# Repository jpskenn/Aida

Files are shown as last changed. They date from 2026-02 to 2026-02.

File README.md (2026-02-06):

# Aida（アイーダ）

Yet another split keyboard, based on SandyLP.

Aida is a 40% split keyboard with symmetrical row staggered layout and key height optimization.

---

Aidaは左右対称ロースタッガード配列の40%分割型キーボードで、スイッチの配置を立体的にして高さ方向への最適化をおこなっています。

前機種の[SandyLP](https://github.com/jpskenn/SandyLP)を元に、分割型へ派生しました。

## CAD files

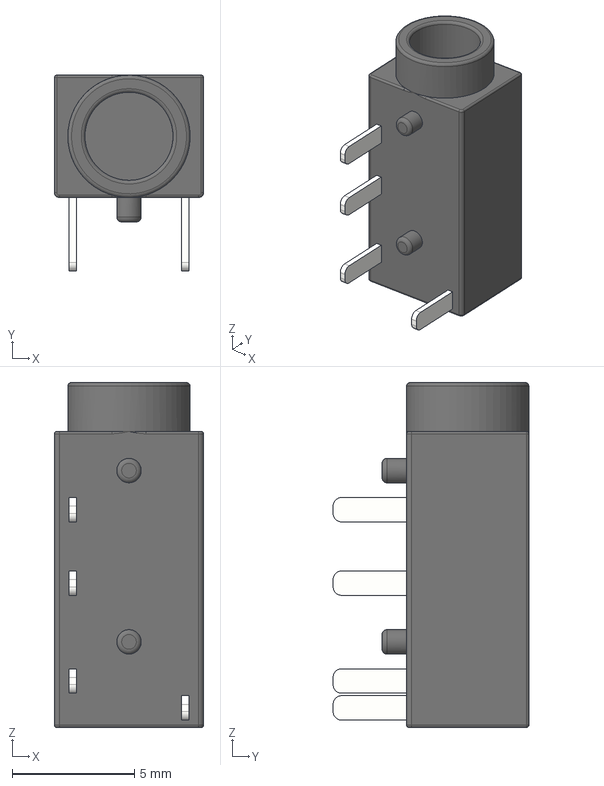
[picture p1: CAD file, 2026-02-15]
PCB/Aida_Under_Cover/Lib_Local/PJ-320A.step
6.10 x 8.00 x 14.1 mm

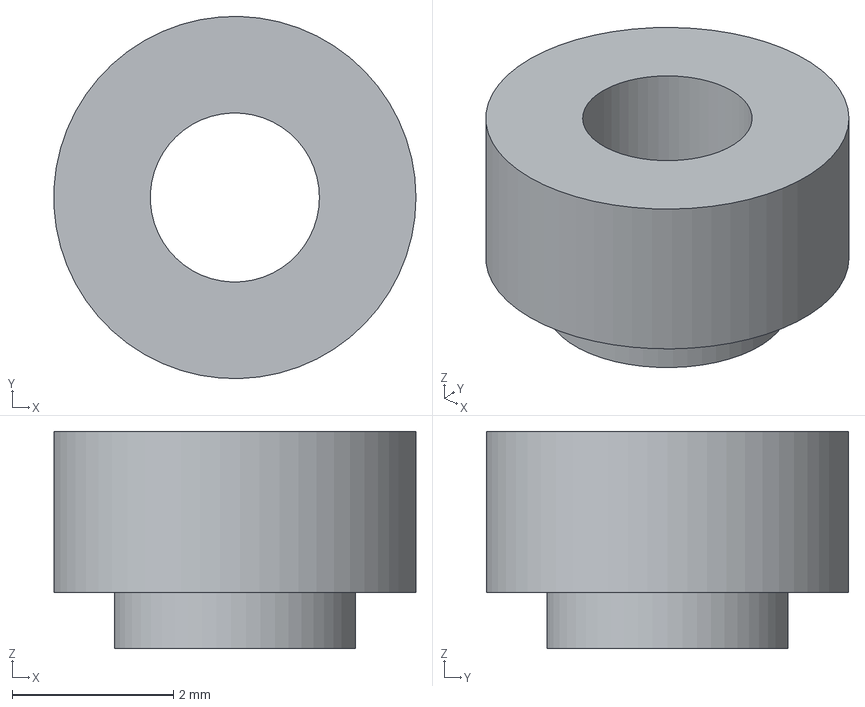
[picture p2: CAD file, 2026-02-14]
PCB/Aida_Under_Cover/Lib_Local/ThroughHole-Tap_THC-0.8-2.0-2-Fusion.step
4.50 x 4.50 x 2.70 mm

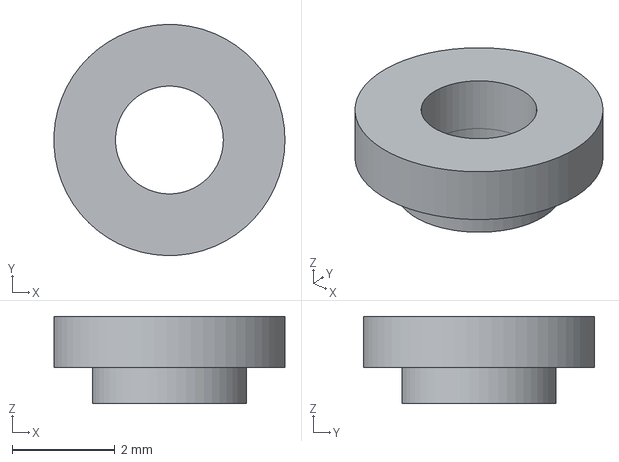
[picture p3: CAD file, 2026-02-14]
PCB/Aida_Under_Cover/Lib_Local/ThroughHole-Tap_THC-0.8-1.0-2-Fusion.step
4.50 x 4.50 x 1.70 mm

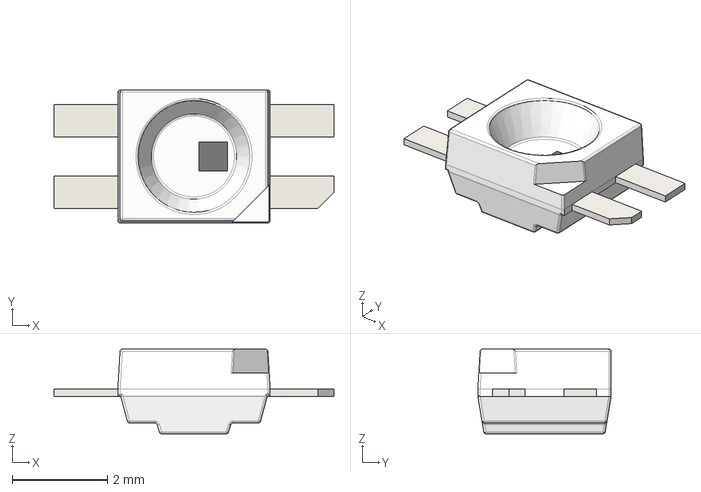
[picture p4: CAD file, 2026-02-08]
PCB/Aida_Under_Cover/Lib_Local/LED_SK6812MINI-E.step
5.88 x 2.80 x 1.78 mm

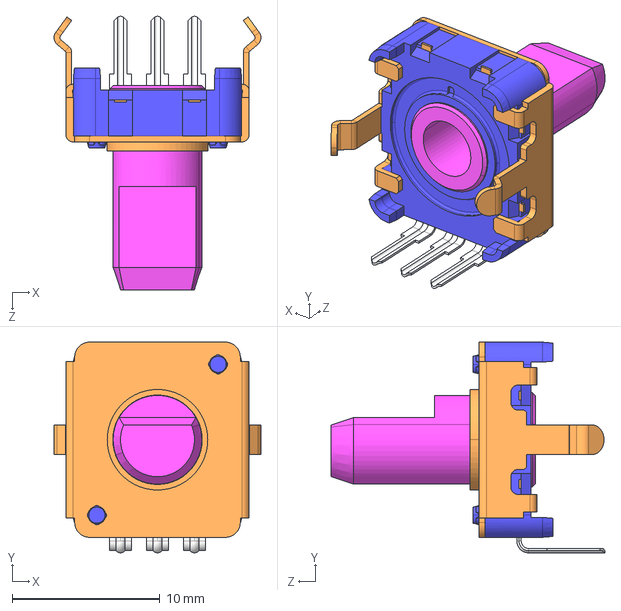
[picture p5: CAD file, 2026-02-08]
PCB/Aida_Under_Cover/Lib_Local/EC12E-150.STEP
14.0 x 14.2 x 18.5 mm

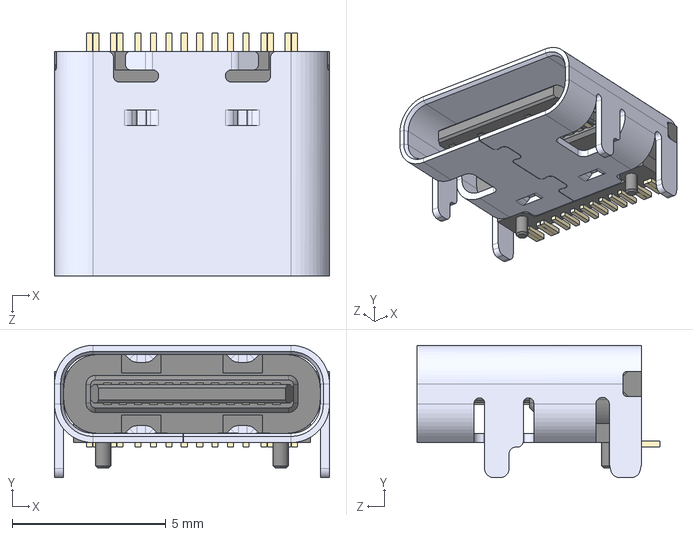
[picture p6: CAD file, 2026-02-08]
PCB/Aida_Under_Cover/Lib_Local/TYPE-C-31-M-12--3DModel-STEP-56544.STEP
8.94 x 4.30 x 7.90 mm

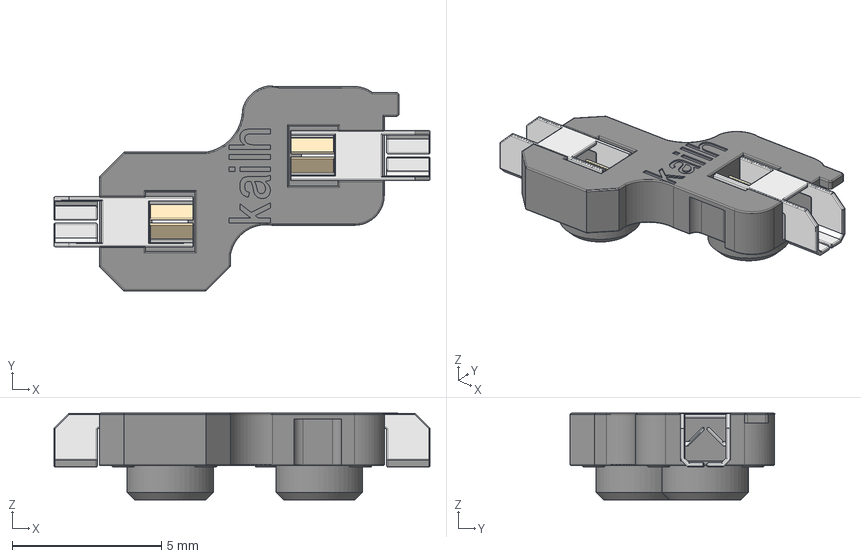
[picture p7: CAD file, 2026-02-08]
PCB/Aida_Under_Cover/Lib_Local/kailh-socket-choc.stp
12.6 x 6.87 x 2.90 mm
metal-contact1
metal-contact2
plastic-body

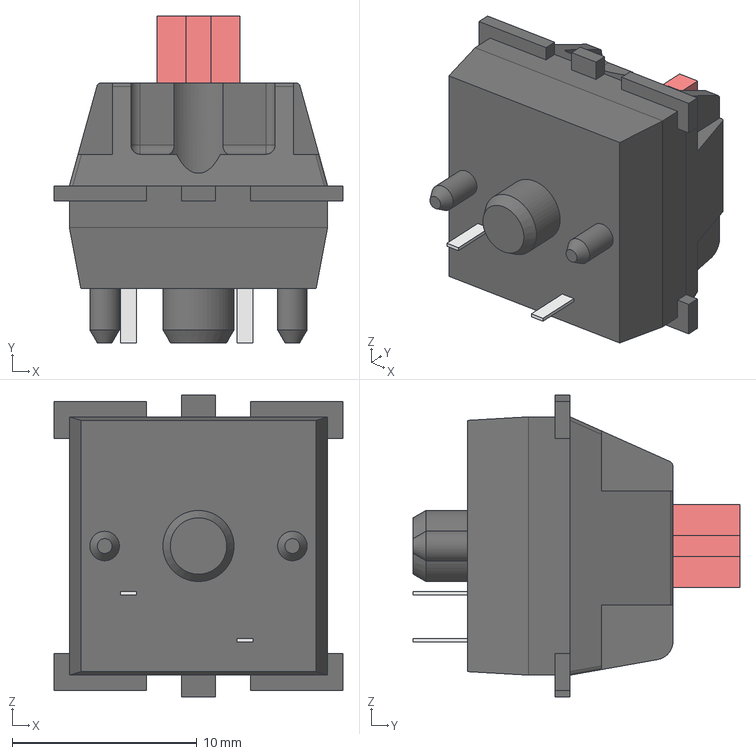
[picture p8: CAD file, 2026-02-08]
PCB/Aida_Under_Cover/Lib_Local/mx-switch.step
15.6 x 17.7 x 16.3 mm

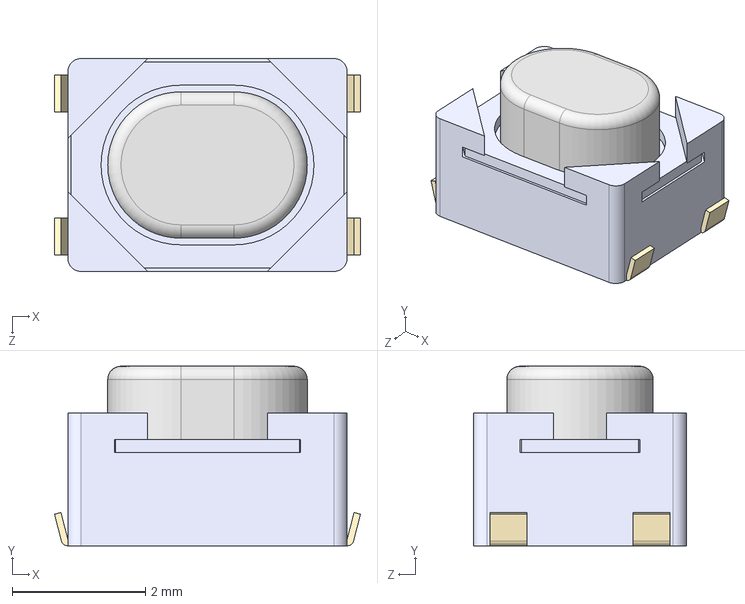
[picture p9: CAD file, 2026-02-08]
PCB/Aida_Under_Cover/Lib_Local/PTS810_SJM_250_SMTR_LFS.step
4.60 x 2.70 x 3.20 mm

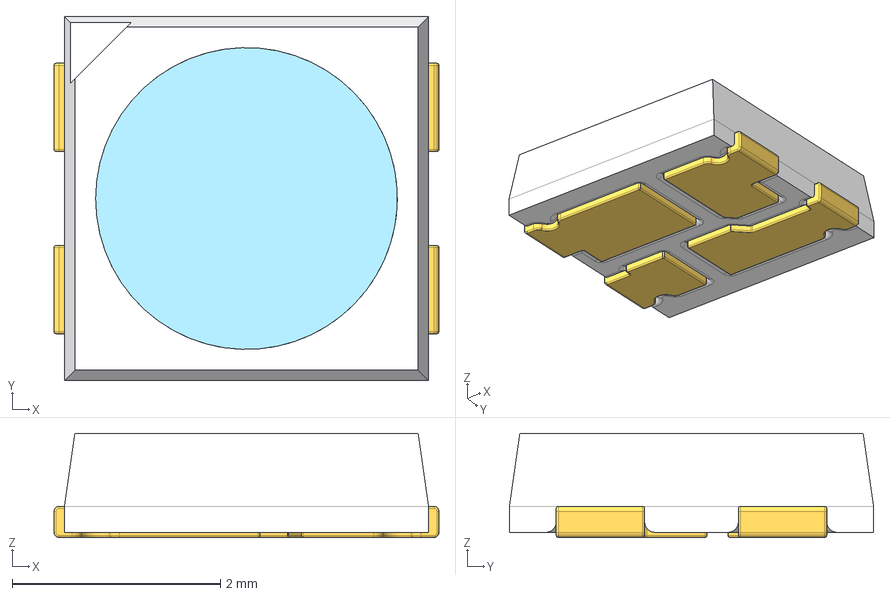
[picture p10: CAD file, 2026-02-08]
PCB/Aida_Under_Cover/Lib_Local/SMD3535 RGB.stp
3.70 x 3.50 x 1.00 mm

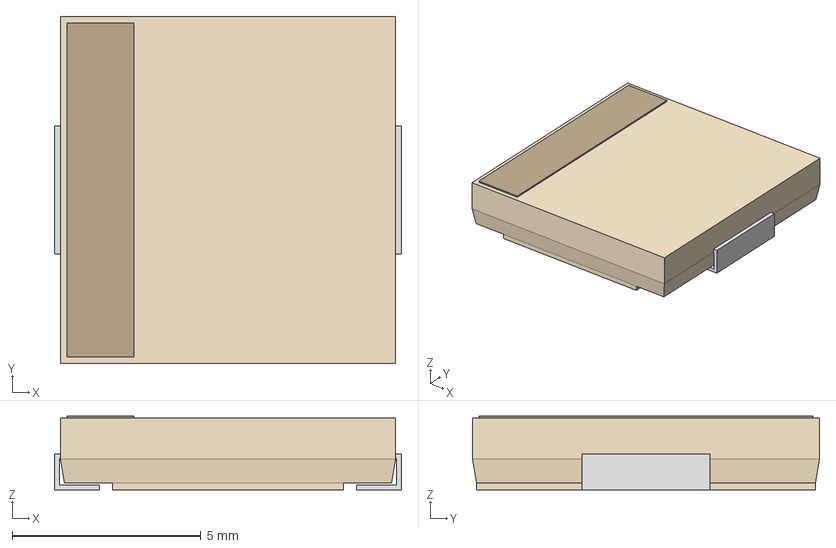
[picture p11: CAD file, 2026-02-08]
PCB/Aida_Under_Cover/Lib_Local/PKMCS0909E4000-R1_MUR.step
9.19 x 9.19 x 1.96 mm

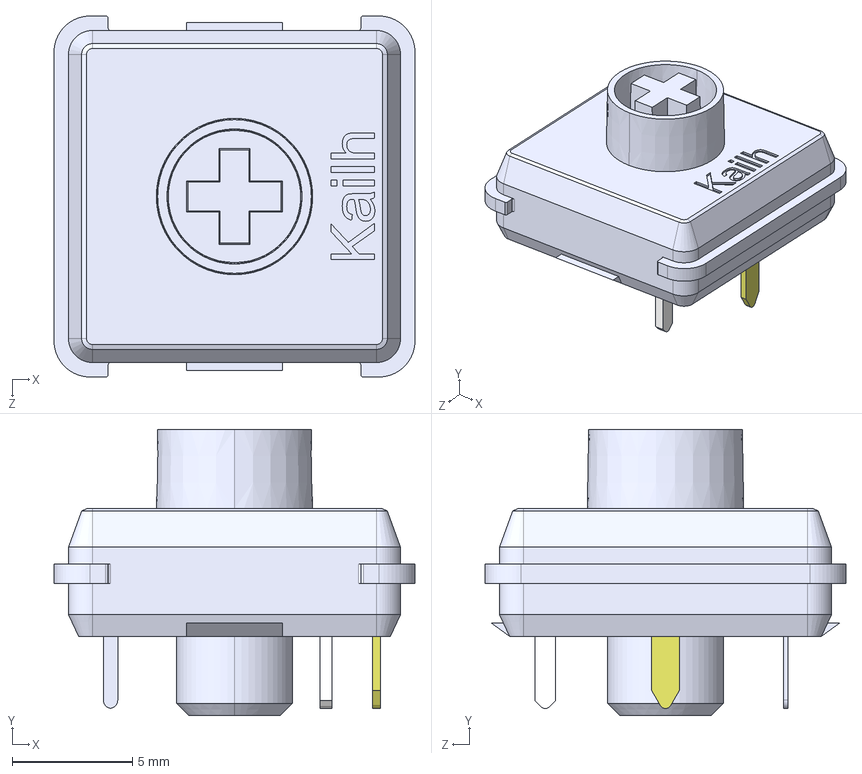
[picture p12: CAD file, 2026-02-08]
PCB/Aida_Under_Cover/Lib_Local/Kailh_PG1353.STEP
15.0 x 11.9 x 15.0 mm

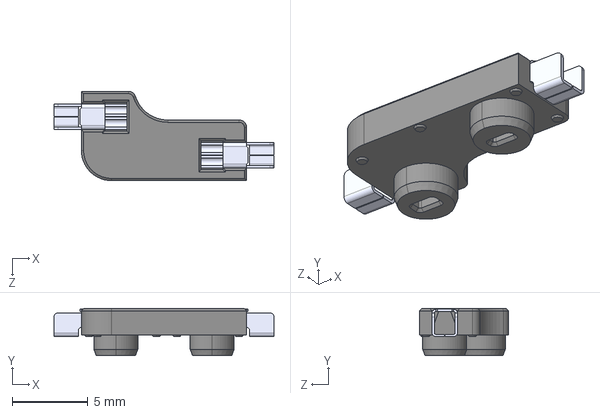
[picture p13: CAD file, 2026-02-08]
PCB/Aida_Under_Cover/Lib_Local/MX_Socket_PG151101S11.STEP
14.5 x 3.10 x 5.89 mm

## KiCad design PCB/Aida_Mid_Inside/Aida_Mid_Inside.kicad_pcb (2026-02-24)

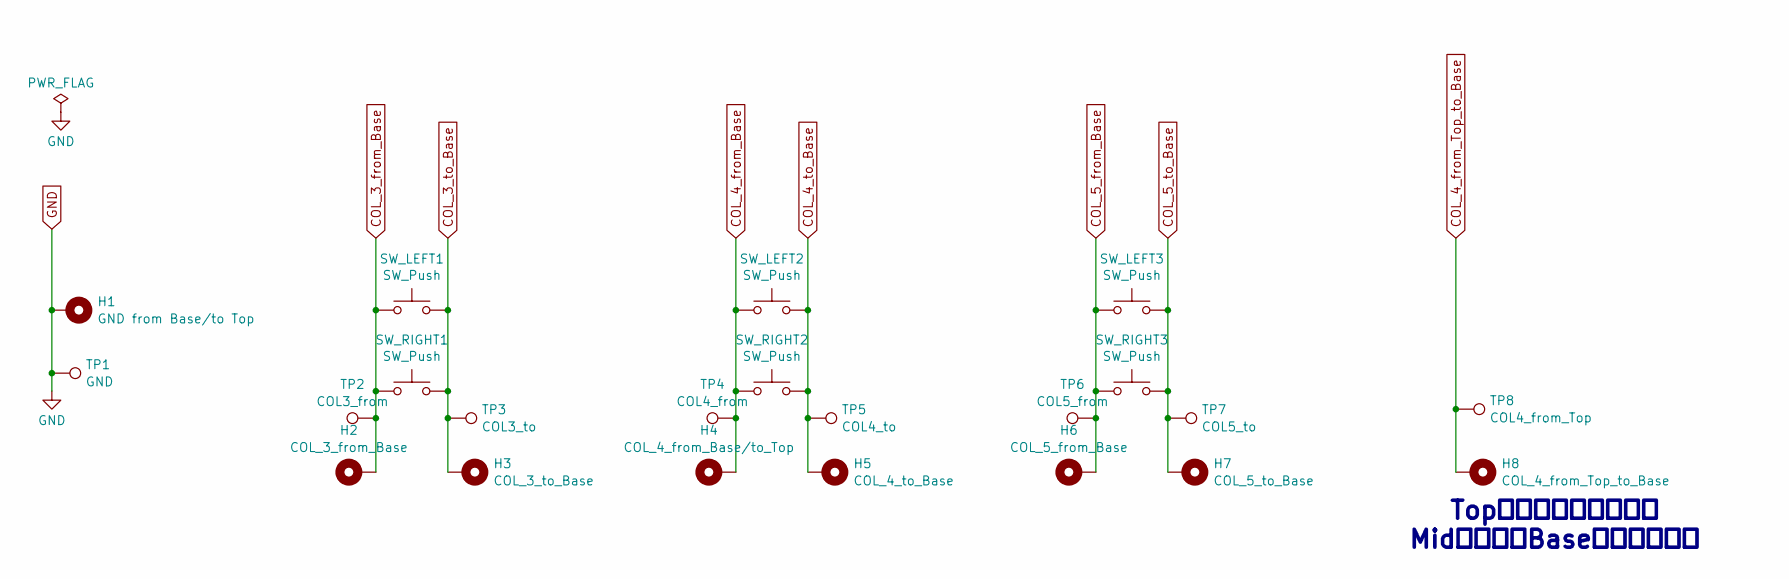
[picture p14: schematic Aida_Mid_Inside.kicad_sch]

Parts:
H1: GND from Base/to Top; MountingHole_2.2mm_M2_Pad_minimal
H2: COL_3_from_Base; MountingHole_M2_Through-hole_tap_THC-0.8-1.0-2_minimal
H3: COL_3_to_Base; MountingHole_M2_Through-hole_tap_THC-0.8-1.0-2_minimal
H4: COL_4_from_Base/to_Top; MountingHole_2.2mm_M2_Pad_minimal
H5: COL_4_to_Base; MountingHole_M2_Through-hole_tap_THC-0.8-1.0-2_minimal
H6: COL_5_from_Base; MountingHole_2.2mm_M2_Pad_minimal
H7: COL_5_to_Base; MountingHole_2.2mm_M2_Pad_minimal
H8: COL_4_from_Top_to_Base; MountingHole_2.2mm_M2_Pad_minimal
SW_LEFT1, SW_LEFT2, SW_LEFT3: SW_Push; Kailh_socket_ChocV2_small_#2pad_for_Reverse_no_hole
SW_RIGHT1, SW_RIGHT2, SW_RIGHT3: SW_Push; Kailh_socket_ChocV2_for_Reverse
TP1: GND; PinHeader_1x01_P2.00mm_Vertical
TP2: COL3_from; PinHeader_1x01_P2.00mm_Vertical
TP3: COL3_to; PinHeader_1x01_P2.00mm_Vertical
TP4: COL4_from; PinHeader_1x01_P2.00mm_Vertical
TP5: COL4_to; PinHeader_1x01_P2.00mm_Vertical
TP6: COL5_from; PinHeader_1x01_P2.00mm_Vertical
TP7: COL5_to; PinHeader_1x01_P2.00mm_Vertical
TP8: COL4_from_Top; PinHeader_1x01_P2.00mm_Vertical

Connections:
COL_3_from_Base: H2.1, SW_LEFT1.1, SW_RIGHT1.1, TP2.1
COL_3_to_Base: H3.1, SW_LEFT1.2, SW_RIGHT1.2, TP3.1
COL_4_from_Base: H4.1, SW_LEFT2.1, SW_RIGHT2.1, TP4.1
COL_4_from_Top_to_Base: H8.1, TP8.1
COL_4_to_Base: H5.1, SW_LEFT2.2, SW_RIGHT2.2, TP5.1
COL_5_from_Base: H6.1, SW_LEFT3.1, SW_RIGHT3.1, TP6.1
COL_5_to_Base: H7.1, SW_LEFT3.2, SW_RIGHT3.2, TP7.1
GND: H1.1, TP1.1

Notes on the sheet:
Topのスイッチ出力は、 Midとは別にBaseへ伝達する。

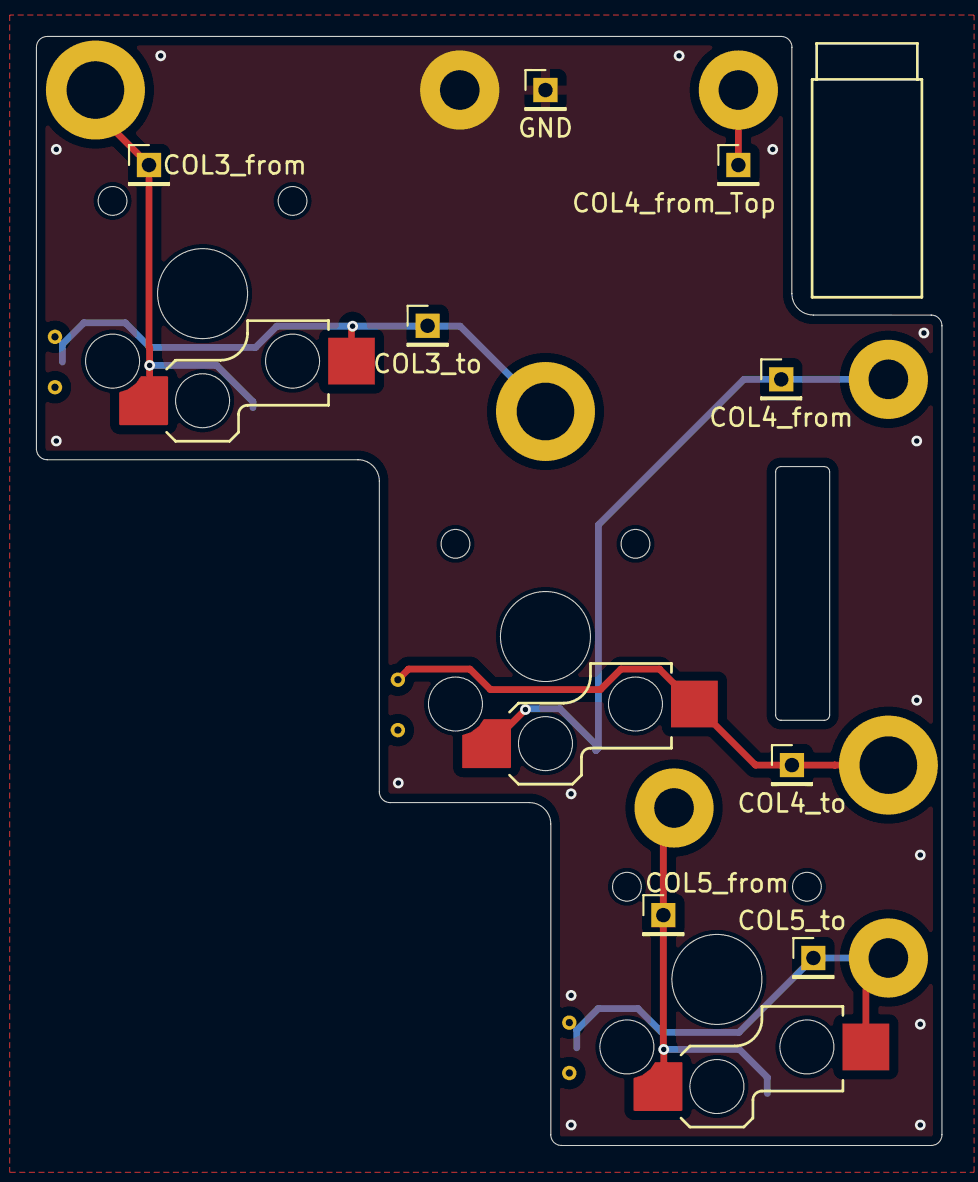
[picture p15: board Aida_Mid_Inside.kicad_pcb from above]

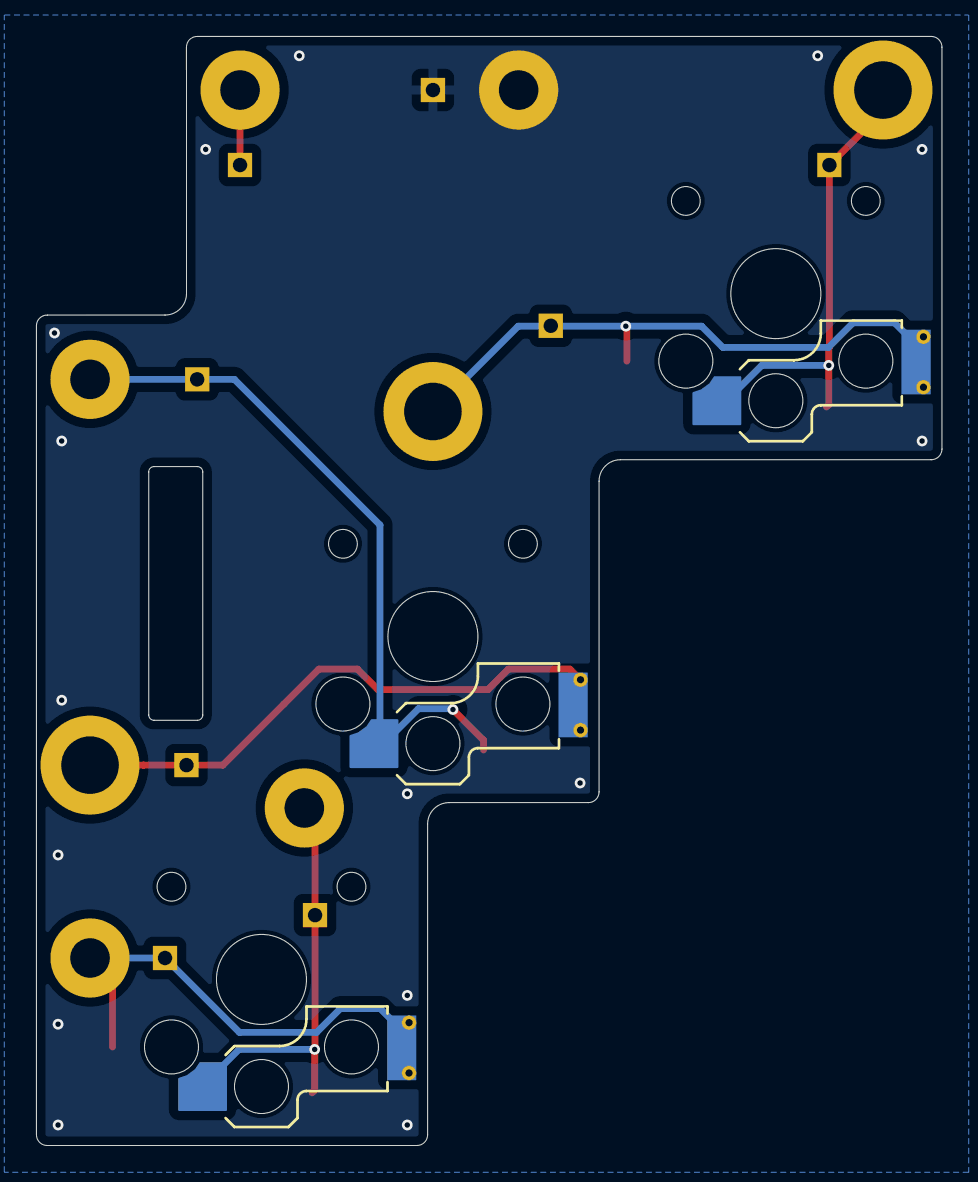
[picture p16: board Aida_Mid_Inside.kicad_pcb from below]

Board: 2 copper layers, 50.3 x 61.6 mm, 22 parts (3 on the bottom side), 8 nets.

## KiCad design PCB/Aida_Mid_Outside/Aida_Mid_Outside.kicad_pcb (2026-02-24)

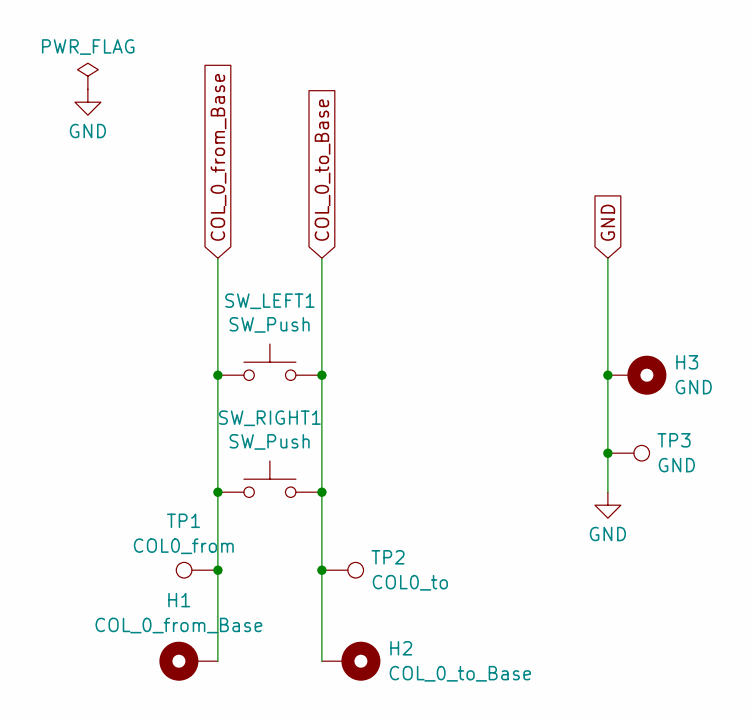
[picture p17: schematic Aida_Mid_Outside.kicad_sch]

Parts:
H1: COL_0_from_Base; MountingHole_2.2mm_M2_Pad_minimal
H2: COL_0_to_Base; MountingHole_M2_Through-hole_tap_THC-0.8-1.0-2_minimal
H3: GND; MountingHole_M2_Through-hole_tap_THC-0.8-1.0-2_minimal
SW_LEFT1: SW_Push; Kailh_socket_ChocV2_for_Reverse
SW_RIGHT1: SW_Push; Kailh_socket_ChocV2_small_#2pad_for_Reverse_no_hole
TP1: COL0_from; PinHeader_1x01_P2.00mm_Vertical
TP2: COL0_to; PinHeader_1x01_P2.00mm_Vertical
TP3: GND; PinHeader_1x01_P2.00mm_Vertical

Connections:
COL_0_from_Base: H1.1, SW_LEFT1.1, SW_RIGHT1.1, TP1.1
COL_0_to_Base: H2.1, SW_LEFT1.2, SW_RIGHT1.2, TP2.1
GND: H3.1, TP3.1

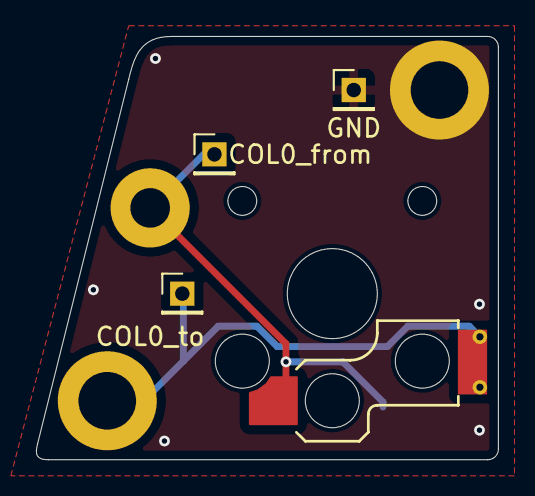
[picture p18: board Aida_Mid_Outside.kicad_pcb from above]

Board: 2 copper layers, 25.7 x 23.5 mm, 8 parts (1 on the bottom side), 3 nets.

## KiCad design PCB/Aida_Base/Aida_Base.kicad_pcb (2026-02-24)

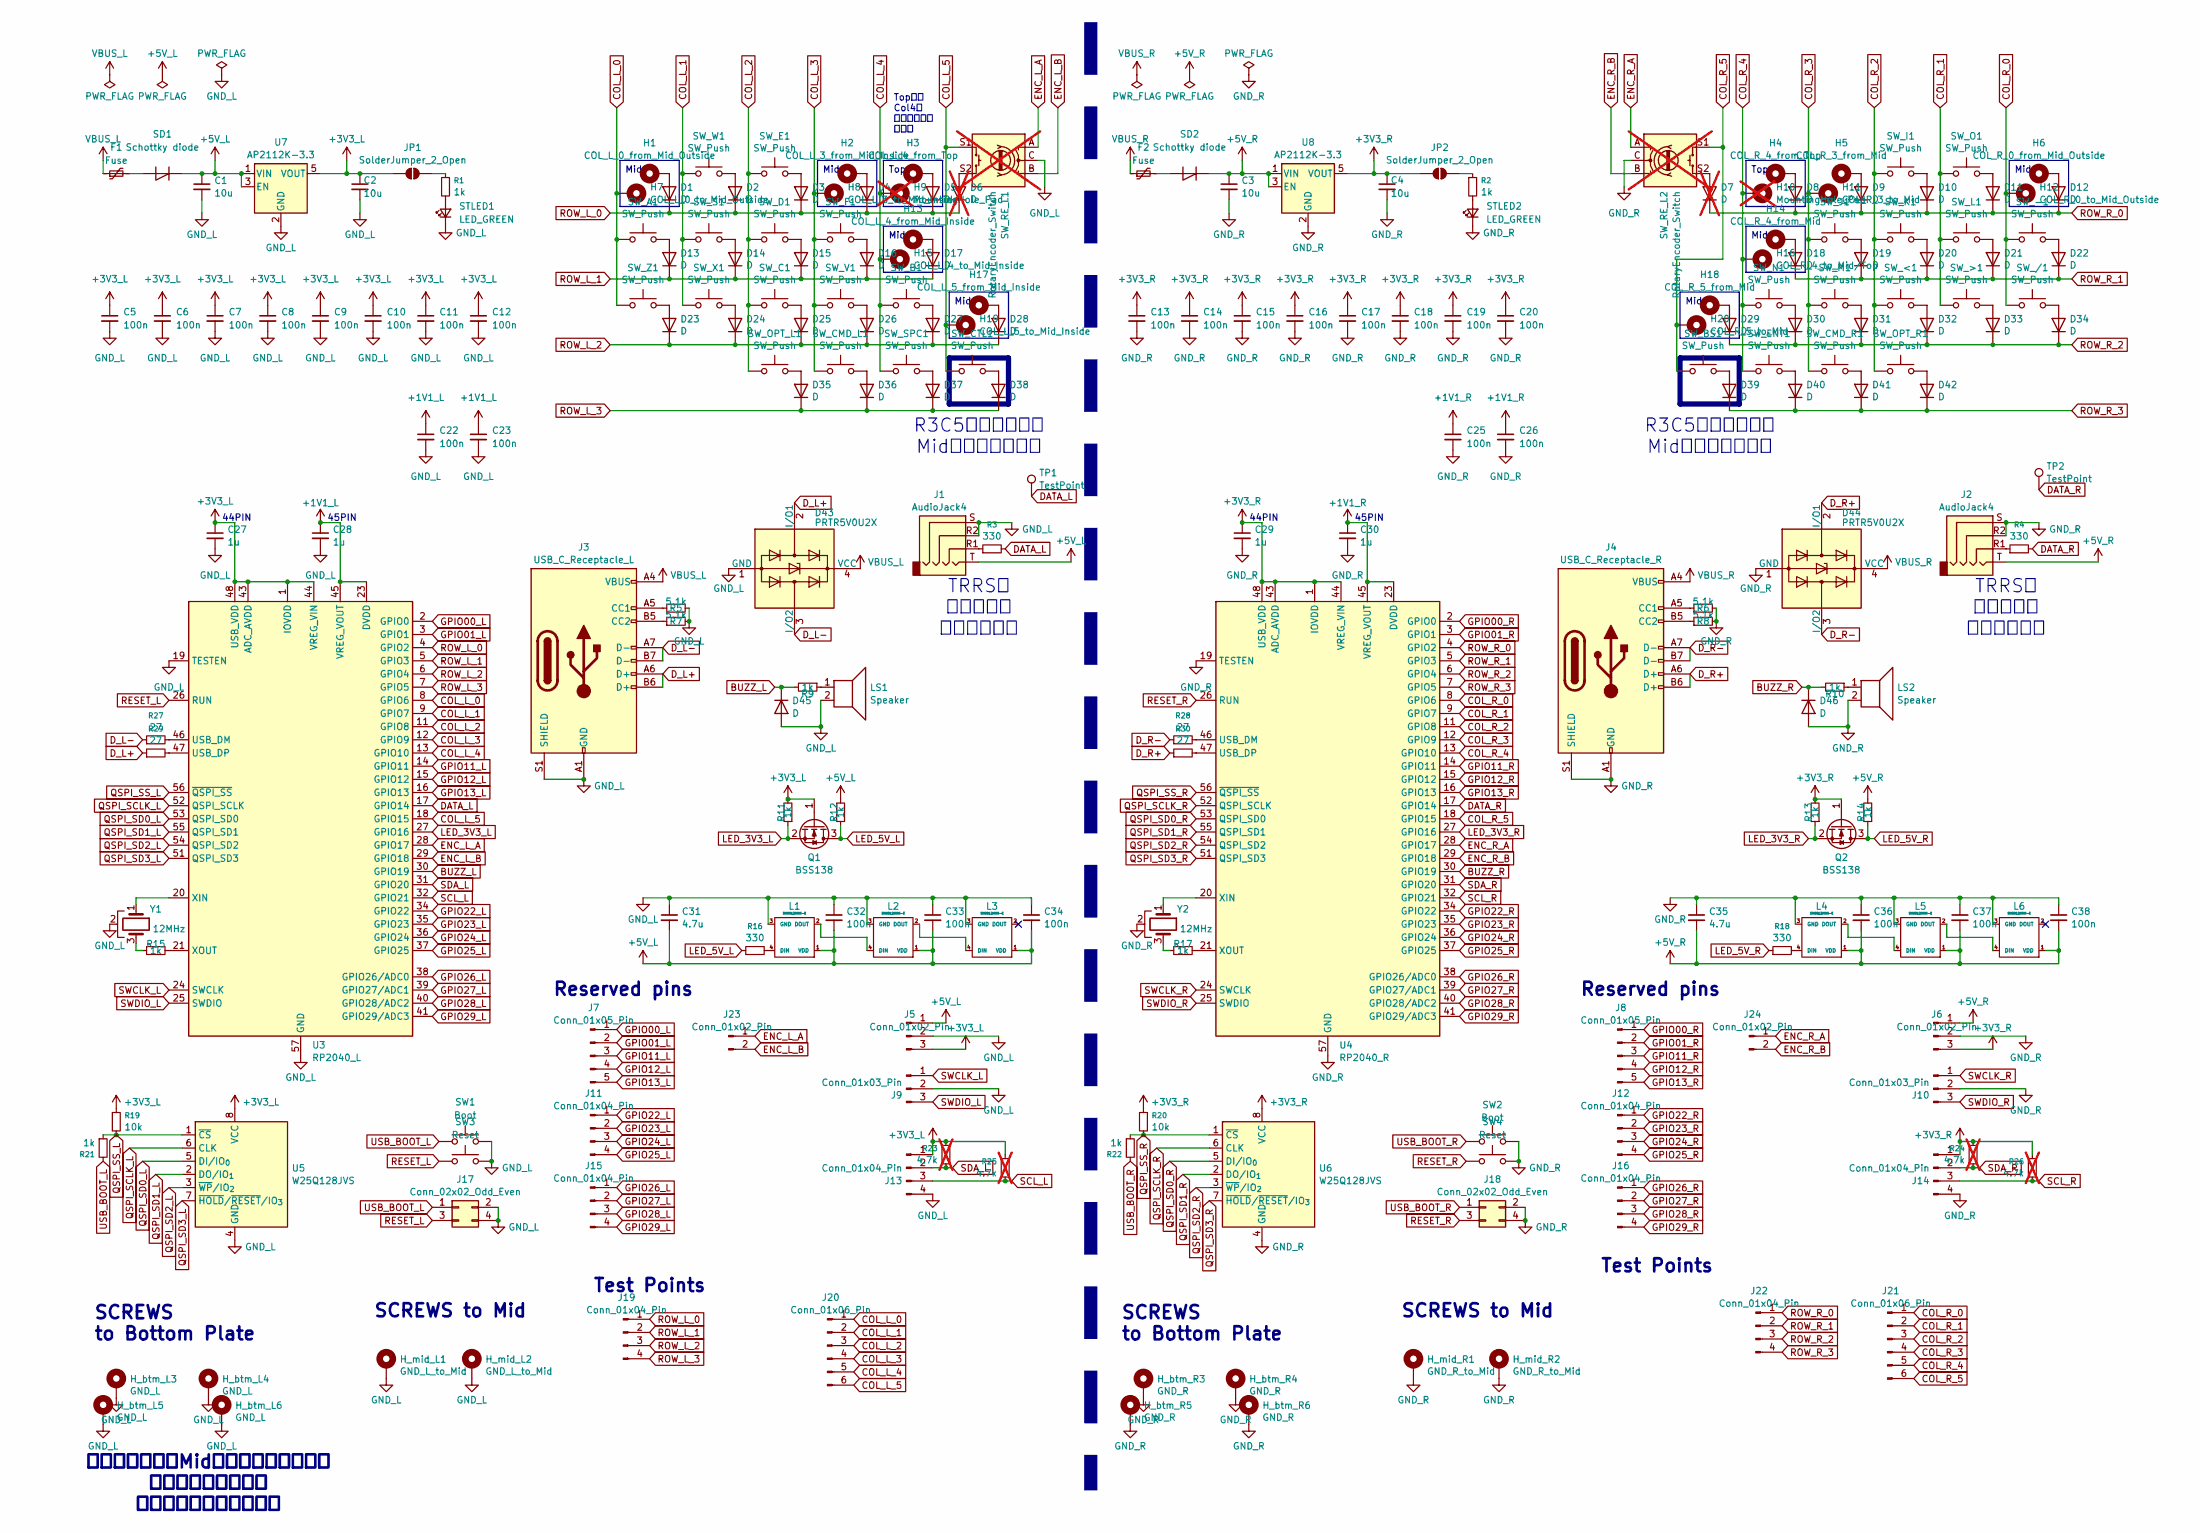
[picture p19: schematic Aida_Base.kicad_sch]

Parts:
C1, C2, C3, C4: 10u; C_0402_1005Metric; LCSC C15525
C5, C6, C7, C8, C9, C10, C11, C12, C13, C14, C15, C16, C17, C18, C19, C20, C22, C23, C25, C26: 100n; C_0402_1005Metric
C27, C28, C29, C30: 1u; C_0402_1005Metric
C31, C35: 4.7u; C_0402_1005Metric; LCSC C1525
C32, C33, C34, C36, C37, C38: 100n; C_0402_1005Metric; LCSC C1525
D1, D2, D3, D4, D5, D8, D9, D10, D11, D12, D13, D14, D15, D16, D17, D18, D19, D20, D21, D22, D23, D24, D25, D26, D27, D28, D29, D30, D31, D32, D33, D34, D35, D36, D37, D38, D39, D40, D41, D42: D; D_SOD-123_Emphasized_Direction_Line; LCSC C81598
D6, D7: D; D_SOD-123_Emphasized_Direction_Line; LCSC C81598; not fitted
D43, D44: PRTR5V0U2X; SOT-143; LCSC C78442
D45, D46: D; D_SOD-123_Emphasized_Direction_Line
F1, F2: Fuse; Fuse_0603_1608Metric; LCSC C187605
H1: COL_L_0_from_Mid_Outside; MountingHole_M2_Through-hole_tap_THC-0.8-2.0-2_minimal
H2: COL_L_3_from_Mid_Inside; MountingHole_M2_Through-hole_tap_THC-0.8-2.0-2_minimal
H3: COL_L_4_from_Top; MountingHole_M2_Through-hole_tap_THC-0.8-2.0-2_minimal
H4: COL_R_4_from_Top; MountingHole_M2_Through-hole_tap_THC-0.8-2.0-2_minimal
H5: COL_R_3_from_Mid; MountingHole_M2_Through-hole_tap_THC-0.8-2.0-2_minimal
H6: COL_R_0_from_Mid_Outside; MountingHole_M2_Through-hole_tap_THC-0.8-2.0-2_minimal
H7: COL_L_0_to_Mid_Outside; MountingHole_M2_Through-hole_tap_THC-0.8-2.0-2_minimal
H8: COL_L_3_to_Mid_Inside; MountingHole_M2_Through-hole_tap_THC-0.8-2.0-2_minimal
H9, H10: MountingHole_Pad; MountingHole_1.8-2.2mm_M2_Pad_minimal; not fitted
H11: COL_R_3_to_Mid; MountingHole_M2_Through-hole_tap_THC-0.8-2.0-2_minimal
H12: COL_R_0_to_Mid_Outside; MountingHole_M2_Through-hole_tap_THC-0.8-2.0-2_minimal
H13: COL_L_4_from_Mid_Inside; MountingHole_M2_Through-hole_tap_THC-0.8-2.0-2_minimal
H14: COL_R_4_from_Mid; MountingHole_M2_Through-hole_tap_THC-0.8-2.0-2_minimal
H15: COL_L_4_to_Mid_Inside; MountingHole_M2_Through-hole_tap_THC-0.8-2.0-2_minimal
H16: COL_R_4_to_Mid/Top; MountingHole_M2_Through-hole_tap_THC-0.8-2.0-2_minimal
H17: COL_L_5_from_Mid_Inside; MountingHole_M2_Through-hole_tap_THC-0.8-2.0-2_minimal
H18: COL_R_5_from_Mid; MountingHole_M2_Through-hole_tap_THC-0.8-2.0-2_minimal
H19: COL_L_5_to_Mid_Inside; MountingHole_M2_Through-hole_tap_THC-0.8-2.0-2_minimal
H20: COL_R_5_to_Mid; MountingHole_M2_Through-hole_tap_THC-0.8-2.0-2_minimal
H_btm_L3, H_btm_L4, H_btm_L5, H_btm_L6: GND_L; MountingHole_M2_Through-hole_tap_THC-0.8-1.0-2_minimal
H_btm_R3, H_btm_R4, H_btm_R5, H_btm_R6: GND_R; MountingHole_M2_Through-hole_tap_THC-0.8-1.0-2_minimal
H_mid_L1, H_mid_L2: GND_L_to_Mid; MountingHole_M2_Through-hole_tap_THC-0.8-1.0-2_minimal
H_mid_R1, H_mid_R2: GND_R_to_Mid; MountingHole_M2_Through-hole_tap_THC-0.8-1.0-2_minimal
J1, J2: AudioJack4; TRRS-PJ-320A_PinNameChanged
J3: USB_C_Receptacle_L; USB_C_Receptacle_HRO_TYPE-C-31-M-12
J4: USB_C_Receptacle_R; USB_C_Receptacle_HRO_TYPE-C-31-M-12
J5, J6: Conn_01x02_Pin; PinHeader_1x03_P2.00mm_Vertical
J7, J8: Conn_01x05_Pin; PinHeader_1x05_P1.00mm_Vertical
J9, J10: Conn_01x03_Pin; PinHeader_1x03_P2.54mm_Vertical
J11, J12, J15, J16: Conn_01x04_Pin; PinHeader_1x04_P1.00mm_Vertical
J13, J14: Conn_01x04_Pin; PinHeader_1x04_P2.54mm_Vertical
J17, J18: Conn_02x02_Odd_Even; PinHeader_2x02_P2.00mm_Vertical
J19, J22: Conn_01x04_Pin; PinHeader_1x04_P2.00mm_Vertical
J20, J21: Conn_01x06_Pin; PinHeader_1x06_P2.00mm_Vertical
J23, J24: Conn_01x02_Pin; PinHeader_1x02_P2.00mm_Vertical
JP1, JP2: SolderJumper_2_Open; SolderJumper-2_P1.3mm_Open_RoundedPad1.0x1.5mm
L1, L2, L3, L4, L5, L6: SK6812MINI-E; YS-SK6812MINI-E_middle_hole_with_small_pad_NPTH
LS1, LS2: Speaker; Buzzer_Murata_PKMCS0909E; LCSC-Reserve C910763
Q1, Q2: BSS138; SOT-23; LCSC C78284
R1, R2, R15, R17, R21, R22: 1k; R_0402_1005Metric
R3, R4, R16, R18: 330; R_0402_1005Metric
R5, R6, R7, R8: 5.1k; R_0402_1005Metric
R9, R10, R11, R12, R13, R14: 1k; R_0402_1005Metric; LCSC C11702
R19, R20: 10k; R_0402_1005Metric
R23, R24, R25, R26: 4.7k; R_0402_1005Metric; not fitted
R27, R28, R29, R30: 27; R_0402_1005Metric
SD1, SD2: Schottky diode; D_SOD-123; LCSC C8598
STLED1, STLED2: LED_GREEN; LED_0201_0603Metric_Pad0.64x0.40mm_HandSolder
SW1, SW2: Boot; SW_SPST_PTS810
SW3, SW4: Reset; SW_SPST_PTS810
SW_-1: SW_Push; Kailh_socket_ChocV2_for_T=1.2mmPCB
SW_/1: SW_Push; Kailh_socket_ChocV2_for_T=1.2mmPCB
SW_<1: SW_Push; Kailh_socket_ChocV2_for_T=1.2mmPCB
SW_>1: SW_Push; Kailh_socket_ChocV2_for_T=1.2mmPCB
SW_A1: SW_Push; Kailh_socket_ChocV2_for_T=1.2mmPCB
SW_B1: SW_Push; Kailh_socket_ChocV2_for_T=1.2mmPCB
SW_BS1: SW_Push; Kailh_socket_ChocV2_for_T=1.2mmPCB
SW_C1: SW_Push; Kailh_socket_ChocV2_for_T=1.2mmPCB
SW_CMD_L1: SW_Push; Kailh_socket_ChocV2_for_T=1.2mmPCB
SW_CMD_R1: SW_Push; Kailh_socket_ChocV2_for_T=1.2mmPCB
SW_CTL1: SW_Push; Kailh_socket_ChocV2_for_T=1.2mmPCB
SW_D1: SW_Push; Kailh_socket_ChocV2_for_T=1.2mmPCB
SW_E1: SW_Push; Kailh_socket_ChocV2_for_T=1.2mmPCB
SW_ENT1: SW_Push; Kailh_socket_ChocV2_for_T=1.2mmPCB
SW_F1: SW_Push; Kailh_socket_ChocV2_for_T=1.2mmPCB
SW_I1: SW_Push; Kailh_socket_ChocV2_for_T=1.2mmPCB
SW_J1: SW_Push; Kailh_socket_ChocV2_for_T=1.2mmPCB
SW_K1: SW_Push; Kailh_socket_ChocV2_for_T=1.2mmPCB
SW_L1: SW_Push; Kailh_socket_ChocV2_for_T=1.2mmPCB
SW_M1: SW_Push; Kailh_socket_ChocV2_for_T=1.2mmPCB
SW_N1: SW_Push; Kailh_socket_ChocV2_for_T=1.2mmPCB
SW_O1: SW_Push; Kailh_socket_ChocV2_for_T=1.2mmPCB
SW_OPT_L1: SW_Push; Kailh_socket_ChocV2_for_T=1.2mmPCB
SW_OPT_R1: SW_Push; Kailh_socket_ChocV2_for_T=1.2mmPCB
SW_RE_L1, SW_RE_L2: RotaryEncoder_Switch; ChocV2_AND_RotaryEncoder_Alps_EC11K-Switch_Vertical_H20mm_N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; not fitted
SW_S1: SW_Push; Kailh_socket_ChocV2_for_T=1.2mmPCB
SW_SPC1: SW_Push; Kailh_socket_ChocV2_for_T=1.2mmPCB
SW_V1: SW_Push; Kailh_socket_ChocV2_for_T=1.2mmPCB
SW_W1: SW_Push; Kailh_socket_ChocV2_for_T=1.2mmPCB
SW_X1: SW_Push; Kailh_socket_ChocV2_for_T=1.2mmPCB
SW_Z1: SW_Push; Kailh_socket_ChocV2_for_T=1.2mmPCB
TP1, TP2: TestPoint; PinHeader_1x01_P2.00mm_Vertical
U3: RP2040_L; RP2040-QFN-56
U4: RP2040_R; RP2040-QFN-56
U5, U6: W25Q128JVS; SOIC-8_5.3x5.3mm_P1.27mm
U7, U8: AP2112K-3.3; SOT-23-5
Y1, Y2: 12MHz; Resonator_SMD_Murata_CSTxExxV-3Pin_3.0x1.1mm

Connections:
+1V1_L: C22.1, C23.1, C28.1, U3.23 (DVDD), U3.45 (VREG_VOUT), U3.50 (DVDD)
+1V1_R: C25.1, C26.1, C30.1, U4.23 (DVDD), U4.45 (VREG_VOUT), U4.50 (DVDD)
+3V3_L: C2.1, C5.1, C6.1, C7.1, C8.1, C9.1, C10.1, C11.1, C12.1, C27.1, J5.3, J13.1, JP1.1 (A), Q1.1 (G), R11.2, R19.1, R23.1, R25.2, U3.1 (IOVDD), U3.10 (IOVDD), U3.22 (IOVDD), U3.33 (IOVDD), U3.42 (IOVDD), U3.43 (ADC_AVDD), U3.44 (VREG_VIN), U3.48 (USB_VDD), U3.49 (IOVDD), U5.8 (VCC), U7.5 (VOUT)
+3V3_R: C4.1, C13.1, C14.1, C15.1, C16.1, C17.1, C18.1, C19.1, C20.1, C29.1, J6.3, J14.1, JP2.1 (A), Q2.1 (G), R13.2, R20.1, R24.1, R26.2, U4.1 (IOVDD), U4.10 (IOVDD), U4.22 (IOVDD), U4.33 (IOVDD), U4.42 (IOVDD), U4.43 (ADC_AVDD), U4.44 (VREG_VIN), U4.48 (USB_VDD), U4.49 (IOVDD), U6.8 (VCC), U8.5 (VOUT)
+5V_L: C1.1, C31.2, C32.2, C33.2, C34.2, J1.T, J5.1, L1.1 (VDD), L2.1 (VDD), L3.1 (VDD), R12.2, SD1.1 (K), U7.1 (VIN), U7.3 (EN)
+5V_R: C3.1, C35.2, C36.2, C37.2, C38.2, J2.T, J6.1, L4.1 (VDD), L5.1 (VDD), L6.1 (VDD), R14.2, SD2.1 (K), U8.1 (VIN), U8.3 (EN)
BUZZ_L: D45.1 (K), R9.2, U3.30 (GPIO19)
BUZZ_R: D46.1 (K), R10.2, U4.30 (GPIO19)
COL_L_0: H7.1, J20.1, SW_A1.1, SW_Z1.1, U3.8 (GPIO6)
COL_L_1: J20.2, SW_S1.1, SW_W1.1, SW_X1.1, U3.9 (GPIO7)
COL_L_2: J20.3, SW_C1.1, SW_D1.1, SW_E1.1, SW_OPT_L1.1, U3.11 (GPIO8)
COL_L_3: H8.1, J20.4, SW_CMD_L1.1, SW_F1.1, SW_V1.1, U3.12 (GPIO9)
COL_L_4: H9.1, H15.1, J20.5, SW_B1.1, SW_SPC1.1, U3.13 (GPIO10)
COL_L_5: H19.1, J20.6, SW_CTL1.1, SW_RE_L1.S1, U3.18 (GPIO15)
COL_R_0: H12.1, J21.1, SW_-1.1, SW_/1.1, U4.8 (GPIO6)
COL_R_1: J21.2, SW_>1.1, SW_L1.1, SW_O1.1, U4.9 (GPIO7)
COL_R_2: J21.3, SW_<1.1, SW_I1.1, SW_K1.1, SW_OPT_R1.1, U4.11 (GPIO8)
COL_R_3: H11.1, J21.4, SW_CMD_R1.1, SW_J1.1, SW_M1.1, U4.12 (GPIO9)
COL_R_4: H10.1, H16.1, J21.5, SW_ENT1.1, SW_N1.1, U4.13 (GPIO10)
COL_R_5: H20.1, J21.6, SW_BS1.1, SW_RE_L2.S1, U4.18 (GPIO15)
DATA_L: R3.2, TP1.1, U3.17 (GPIO14)
DATA_R: R4.2, TP2.1, U4.17 (GPIO14)
D_L+: D43.2 (I/O1), J3.A6 (D+), J3.B6 (D+), R29.1
D_L-: D43.3 (I/O2), J3.A7 (D-), J3.B7 (D-), R27.1
D_R+: D44.2 (I/O1), J4.A6 (D+), J4.B6 (D+), R30.1
D_R-: D44.3 (I/O2), J4.A7 (D-), J4.B7 (D-), R28.1
ENC_L_A: J23.1, SW_RE_L1.A, U3.28 (GPIO17)
ENC_L_B: J23.2, SW_RE_L1.B, U3.29 (GPIO18)
ENC_R_A: J24.1, SW_RE_L2.A, U4.28 (GPIO17)
ENC_R_B: J24.2, SW_RE_L2.B, U4.29 (GPIO18)
GND_L: C1.2, C2.2, C5.2, C6.2, C7.2, C8.2, C9.2, C10.2, C11.2, C12.2, C22.2, C23.2, C27.2, C28.2, C31.1, C32.1, C33.1, C34.1, D43.1 (GND), D45.2 (A), H_btm_L3.1, H_btm_L4.1, H_btm_L5.1, H_btm_L6.1, H_mid_L1.1, H_mid_L2.1, J1.R2, J1.S, J3.A1 (GND), J3.A12 (GND), J3.B1 (GND), J3.B12 (GND), J3.S1 (SHIELD), J5.2, J9.2, J13.4, J17.2, J17.4, L1.3 (GND), L2.3 (GND), L3.3 (GND), LS1.2, R5.2, R7.2, STLED1.1 (K), SW1.2, SW3.2, SW_RE_L1.C, U3.19 (TESTEN), U3.57 (GND), U5.4 (GND), U7.2 (GND), Y1.2
GND_R: C3.2, C4.2, C13.2, C14.2, C15.2, C16.2, C17.2, C18.2, C19.2, C20.2, C25.2, C26.2, C29.2, C30.2, C35.1, C36.1, C37.1, C38.1, D44.1 (GND), D46.2 (A), H_btm_R3.1, H_btm_R4.1, H_btm_R5.1, H_btm_R6.1, H_mid_R1.1, H_mid_R2.1, J2.R2, J2.S, J4.A1 (GND), J4.A12 (GND), J4.B1 (GND), J4.B12 (GND), J4.S1 (SHIELD), J6.2, J10.2, J14.4, J18.2, J18.4, L4.3 (GND), L5.3 (GND), L6.3 (GND), LS2.2, R6.2, R8.2, STLED2.1 (K), SW2.2, SW4.2, SW_RE_L2.C, U4.19 (TESTEN), U4.57 (GND), U6.4 (GND), U8.2 (GND), Y2.2
GPIO00_L: J7.1, U3.2 (GPIO0)
GPIO00_R: J8.1, U4.2 (GPIO0)
GPIO01_L: J7.2, U3.3 (GPIO1)
GPIO01_R: J8.2, U4.3 (GPIO1)
GPIO11_L: J7.3, U3.14 (GPIO11)
GPIO11_R: J8.3, U4.14 (GPIO11)
GPIO12_L: J7.4, U3.15 (GPIO12)
GPIO12_R: J8.4, U4.15 (GPIO12)
GPIO13_L: J7.5, U3.16 (GPIO13)
GPIO13_R: J8.5, U4.16 (GPIO13)
GPIO22_L: J11.1, U3.34 (GPIO22)
GPIO22_R: J12.1, U4.34 (GPIO22)
GPIO23_L: J11.2, U3.35 (GPIO23)
GPIO23_R: J12.2, U4.35 (GPIO23)
GPIO24_L: J11.3, U3.36 (GPIO24)
GPIO24_R: J12.3, U4.36 (GPIO24)
GPIO25_L: J11.4, U3.37 (GPIO25)
GPIO25_R: J12.4, U4.37 (GPIO25)
GPIO26_L: J15.1, U3.38 (GPIO26/ADC0)
GPIO26_R: J16.1, U4.38 (GPIO26/ADC0)
GPIO27_L: J15.2, U3.39 (GPIO27/ADC1)
GPIO27_R: J16.2, U4.39 (GPIO27/ADC1)
GPIO28_L: J15.3, U3.40 (GPIO28/ADC2)
GPIO28_R: J16.3, U4.40 (GPIO28/ADC2)
GPIO29_L: J15.4, U3.41 (GPIO29/ADC3)
GPIO29_R: J16.4, U4.41 (GPIO29/ADC3)
LED_3V3_L: Q1.2 (S), R11.1, U3.27 (GPIO16)
LED_3V3_R: Q2.2 (S), R13.1, U4.27 (GPIO16)
LED_5V_L: Q1.3 (D), R12.1, R16.1
LED_5V_R: Q2.3 (D), R14.1, R18.1
unnamed: D1.2 (A), H1.1
unnamed: D2.2 (A), SW_W1.2
unnamed: D3.2 (A), SW_E1.2
unnamed: D4.2 (A), H2.1
unnamed: D5.2 (A), H3.1
unnamed: D6.2 (A), SW_RE_L1.S2
unnamed: D7.2 (A), SW_RE_L2.S2
unnamed: D8.2 (A), H4.1
unnamed: D9.2 (A), H5.1
unnamed: D10.2 (A), SW_I1.2
unnamed: D11.2 (A), SW_O1.2
unnamed: D12.2 (A), H6.1
unnamed: D13.2 (A), SW_A1.2
unnamed: D14.2 (A), SW_S1.2
unnamed: D15.2 (A), SW_D1.2
unnamed: D16.2 (A), SW_F1.2
unnamed: D17.2 (A), H13.1
unnamed: D18.2 (A), H14.1
unnamed: D19.2 (A), SW_J1.2
unnamed: D20.2 (A), SW_K1.2
unnamed: D21.2 (A), SW_L1.2
unnamed: D22.2 (A), SW_-1.2
unnamed: D23.2 (A), SW_Z1.2
unnamed: D24.2 (A), SW_X1.2
unnamed: D25.2 (A), SW_C1.2
unnamed: D26.2 (A), SW_V1.2
unnamed: D27.2 (A), SW_B1.2
unnamed: D28.2 (A), H17.1
unnamed: D29.2 (A), H18.1
unnamed: D30.2 (A), SW_N1.2
unnamed: D31.2 (A), SW_M1.2
unnamed: D32.2 (A), SW_<1.2
unnamed: D33.2 (A), SW_>1.2
unnamed: D34.2 (A), SW_/1.2
unnamed: D35.2 (A), SW_OPT_L1.2
unnamed: D36.2 (A), SW_CMD_L1.2
unnamed: D37.2 (A), SW_SPC1.2
unnamed: D38.2 (A), SW_CTL1.2
unnamed: D39.2 (A), SW_BS1.2
unnamed: D40.2 (A), SW_ENT1.2
unnamed: D41.2 (A), SW_CMD_R1.2
unnamed: D42.2 (A), SW_OPT_R1.2
unnamed: J1.R1, R3.1
unnamed: J2.R1, R4.1
unnamed: J3.A5 (CC1), R5.1
unnamed: J3.B5 (CC2), R7.1
unnamed: J4.A5 (CC1), R6.1
unnamed: J4.B5 (CC2), R8.1
unnamed: JP1.2 (B), R1.1
unnamed: JP2.2 (B), R2.1
unnamed: L1.4 (DIN), R16.2
unnamed: L1.2 (DOUT), L2.4 (DIN)
unnamed: L2.2 (DOUT), L3.4 (DIN)
unnamed: L4.4 (DIN), R18.2
unnamed: L4.2 (DOUT), L5.4 (DIN)
unnamed: L5.2 (DOUT), L6.4 (DIN)
unnamed: LS1.1, R9.1
unnamed: LS2.1, R10.1
unnamed: R15.1, Y1.3
unnamed: R17.1, Y2.3
unnamed: F1.2, SD1.2 (A)
unnamed: F2.2, SD2.2 (A)
unnamed: R1.2, STLED1.2 (A)
unnamed: R2.2, STLED2.2 (A)
unnamed: R27.2, U3.46 (USB_DM)
unnamed: R29.2, U3.47 (USB_DP)
unnamed: U3.20 (XIN), Y1.1
unnamed: R15.2, U3.21 (XOUT)
unnamed: R28.2, U4.46 (USB_DM)
unnamed: R30.2, U4.47 (USB_DP)
unnamed: U4.20 (XIN), Y2.1
unnamed: R17.2, U4.21 (XOUT)
QSPI_SCLK_L: U3.52 (QSPI_SCLK), U5.6 (CLK)
QSPI_SCLK_R: U4.52 (QSPI_SCLK), U6.6 (CLK)
QSPI_SD0_L: U3.53 (QSPI_SD0), U5.5 (DI/IO_{0})
QSPI_SD0_R: U4.53 (QSPI_SD0), U6.5 (DI/IO_{0})
QSPI_SD1_L: U3.55 (QSPI_SD1), U5.2 (DO/IO_{1})
QSPI_SD1_R: U4.55 (QSPI_SD1), U6.2 (DO/IO_{1})
QSPI_SD2_L: U3.54 (QSPI_SD2), U5.3 (~WP/IO_{2})
QSPI_SD2_R: U4.54 (QSPI_SD2), U6.3 (~WP/IO_{2})
QSPI_SD3_L: U3.51 (QSPI_SD3), U5.7 (~HOLD/~RESET/IO_{3})
QSPI_SD3_R: U4.51 (QSPI_SD3), U6.7 (~HOLD/~RESET/IO_{3})
QSPI_SS_L: R19.2, R21.1, U3.56 (~QSPI_SS), U5.1 (~CS)
QSPI_SS_R: R20.2, R22.1, U4.56 (~QSPI_SS), U6.1 (~CS)
RESET_L: J17.3, SW3.1, U3.26 (RUN)
RESET_R: J18.3, SW4.1, U4.26 (RUN)
ROW_L_0: D1.1 (K), D2.1 (K), D3.1 (K), D4.1 (K), D5.1 (K), D6.1 (K), J19.1, U3.4 (GPIO2)
ROW_L_1: D13.1 (K), D14.1 (K), D15.1 (K), D16.1 (K), D17.1 (K), J19.2, U3.5 (GPIO3)
ROW_L_2: D23.1 (K), D24.1 (K), D25.1 (K), D26.1 (K), D27.1 (K), D28.1 (K), J19.3, U3.6 (GPIO4)
ROW_L_3: D35.1 (K), D36.1 (K), D37.1 (K), D38.1 (K), J19.4, U3.7 (GPIO5)
ROW_R_0: D7.1 (K), D8.1 (K), D9.1 (K), D10.1 (K), D11.1 (K), D12.1 (K), J22.1, U4.4 (GPIO2)
ROW_R_1: D18.1 (K), D19.1 (K), D20.1 (K), D21.1 (K), D22.1 (K), J22.2, U4.5 (GPIO3)
ROW_R_2: D29.1 (K), D30.1 (K), D31.1 (K), D32.1 (K), D33.1 (K), D34.1 (K), J22.3, U4.6 (GPIO4)
ROW_R_3: D39.1 (K), D40.1 (K), D41.1 (K), D42.1 (K), J22.4, U4.7 (GPIO5)
SCL_L: J13.3, R25.1, U3.32 (GPIO21)
SCL_R: J14.3, R26.1, U4.32 (GPIO21)
SDA_L: J13.2, R23.2, U3.31 (GPIO20)
SDA_R: J14.2, R24.2, U4.31 (GPIO20)
SWCLK_L: J9.1, U3.24 (SWCLK)
SWCLK_R: J10.1, U4.24 (SWCLK)
SWDIO_L: J9.3, U3.25 (SWDIO)
SWDIO_R: J10.3, U4.25 (SWDIO)
USB_BOOT_L: J17.1, R21.2, SW1.1
USB_BOOT_R: J18.1, R22.2, SW2.1
VBUS_L: D43.4 (VCC), F1.1, J3.A4 (VBUS), J3.A9 (VBUS), J3.B4 (VBUS), J3.B9 (VBUS)
VBUS_R: D44.4 (VCC), F2.1, J4.A4 (VBUS), J4.A9 (VBUS), J4.B4 (VBUS), J4.B9 (VBUS)

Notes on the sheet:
R3C5のスイッチは Midへ配置するかも
SCREWS to Bottom Plate
Reserved pins
TRRSに 保護回路が あってもよい
Test Points
45PIN
Topへの Col4は 下のスイッチ と共通
44PIN
SCREWS to Mid
マトリクス内のMidねじ＝ボトム用ねじ の場合があるので、 こちらは少し減らす予定
Mid
Top

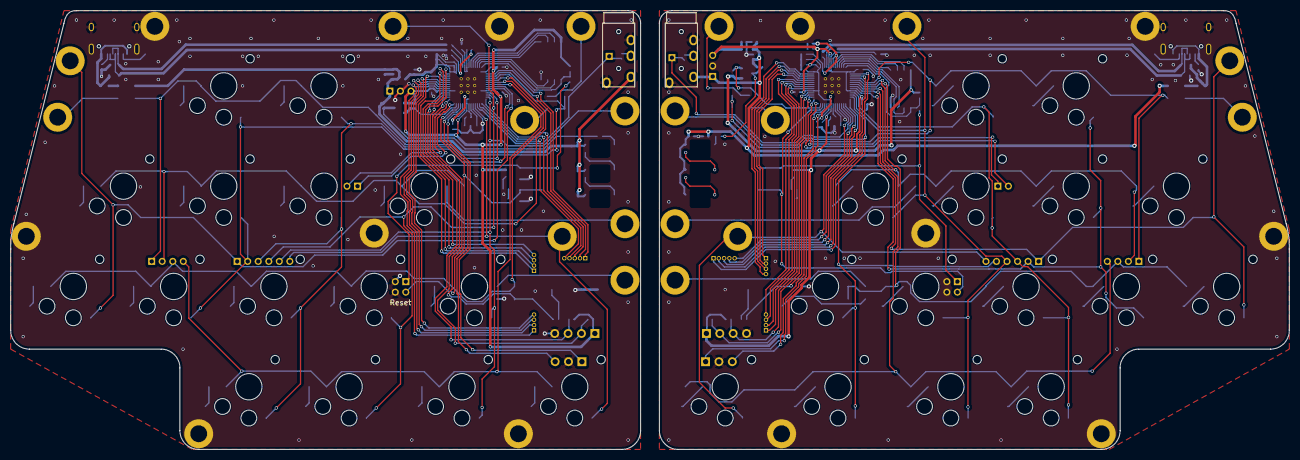
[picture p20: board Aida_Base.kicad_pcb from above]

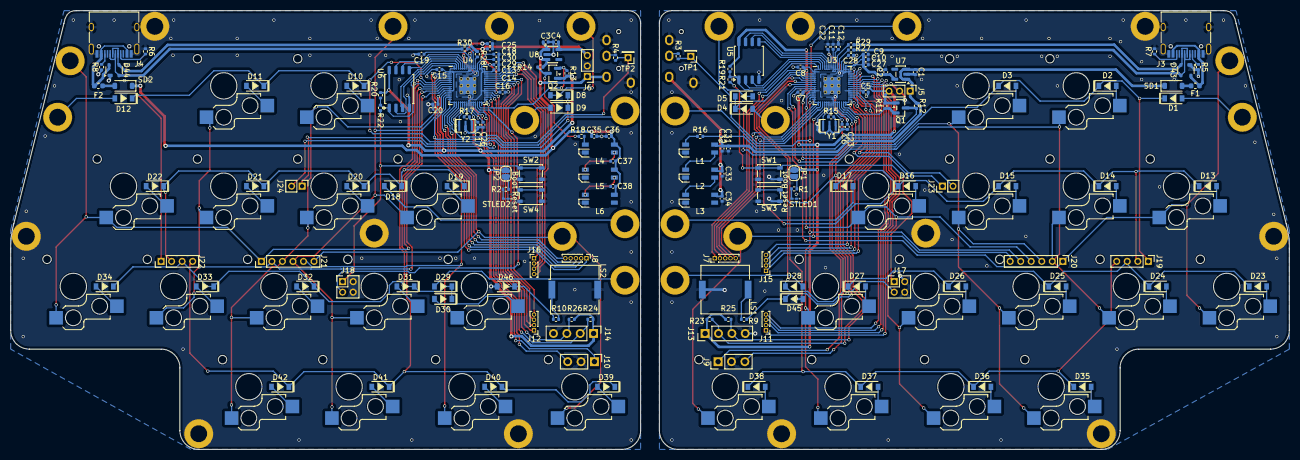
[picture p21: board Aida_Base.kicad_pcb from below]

Board: 2 copper layers, 242.9 x 83.3 mm, 226 parts (164 on the bottom side), 166 nets.

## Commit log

2026-02-06 書き始め
2026-02-08 回路作成中
    [Aida_Base.kicad_pcb, Aida_Base.kicad_sch, EC12E-150.STEP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]
2026-02-11 左手の回路が完成
    [Aida_Base.kicad_sch]
2026-02-11 PCBの部品配置をやり始めた。左右の部品を仕分けした。
    [Aida_Base.kicad_pcb, Aida_Base.kicad_sch]
2026-02-11 左手パーツ配置中。右手マトリクス修正
    [Aida_Base.kicad_pcb, Aida_Base.kicad_sch]
2026-02-13 左手パーツ配置中。ネジ位置で悩み中。
    [Aida_Base.kicad_pcb, Aida_Base.kicad_sch]
2026-02-14 左手パーツ配置中。ネジ位置ほぼ確定。MCUまわり配置中。
    [Aida_Base.kicad_pcb, Aida_Base.kicad_sch, ThroughHole-Tap_THC-0.8-1.0-2-Fusion.step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]
2026-02-15 基板4枚、位置決め完了。
    [Aida_Base.kicad_pcb, Aida_Base.kicad_sch, Aida_Mid_Inside.kicad_pcb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]
2026-02-16 プレート作成中
    [Aida_Base.kicad_pcb, Aida_Mid_Inside.kicad_pcb, Aida_Plate_Base.kicad_pcb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]
2026-02-17 プレート類調整中。LED位置検討中。
    [Aida_Base.kicad_pcb, Aida_Mid_Outside.kicad_pcb, Aida_Plate_Base.kicad_pcb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]
2026-02-17 LED位置、とりあえず決定。
    [Aida_Base.kicad_pcb, Aida_Mid_Inside.kicad_pcb, Aida_Plate_Mid_Inside.kicad_pcb]
2026-02-17 右手パーツ配置中
    [Aida_Base.kicad_pcb, Aida_Base.kicad_sch, Aida_Mid_Inside.kicad_pcb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]
2026-02-17 マトリクス行列のテストポイント追加
    [Aida_Base.kicad_pcb, Aida_Base.kicad_sch]
2026-02-17 左手側配線中
    [Aida_Base.kicad_pcb]
2026-02-19 左手側配線。ほぼ完了。
    [Aida_Base.kicad_pcb, Aida_Base.kicad_sch]
2026-02-21 ボトムプレートの穴あけ用に、左手側パーツ配置調整。
    [Aida_Base.kicad_pcb, Aida_Base.kicad_sch]
2026-02-21 ボトムプレート作成中。基板Baseのパーツ位置調整中。
    [Aida_Base.kicad_pcb, Aida_Bottom.kicad_pcb, Aida_Bottom.kicad_sch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]
2026-02-21 ボトムプレート、一旦完成。
    [Aida_Base.kicad_pcb, Aida_Bottom.kicad_pcb]
2026-02-22 テストポイントを追加、配置した。
    [Aida_Mid_Inside.kicad_pcb, Aida_Mid_Inside.kicad_sch, Aida_Mid_Outside.kicad_pcb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]
2026-02-22 右手パーツ配置中。MCUまわりきびしい
    [Aida_Base.kicad_pcb, Aida_Base.kicad_sch]
2026-02-23 配線すべて繋いだ
    [Aida_Base.kicad_pcb]
2026-02-23 基板Baseのパーツ位置変更に合わせて、プレートの穴を再調整。
    [Aida_Bottom.kicad_pcb]
2026-02-23 ソケットの3Dモデルを、1.2ｍｍ厚のPCBに合わせて位置調整。
    [Aida_Base.kicad_pcb, Aida_Base.kicad_sch]
2026-02-23 ResetとBootスイッチのシルクを追加
    [Aida_Base.kicad_pcb]
2026-02-23 3Dモデルの設定
    [Aida_Base.kicad_pcb]
2026-02-23 USBコネクタ付近の外形変更
    [Aida_Bottom.kicad_pcb]
2026-02-23 ボトムプレートの下にカバーを追加
    [Aida_Under_Cover.kicad_pcb, Aida_Under_Cover.kicad_sch, EC12E-150.STEP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]
2026-02-23 不要データ削除
    [Aida_Base.kicad_pcb]
2026-02-23 LEDのフットプリント変更。配線調整中。
    [Aida_Base.kicad_pcb, Aida_Base.kicad_sch]
2026-02-24 配線調整
    [Aida_Base.kicad_pcb]
2026-02-24 USB配線長を調整した
    [Aida_Base.kicad_pcb]
2026-02-24 原点ガイドを追加。基板Mid_InsideのLED穴形状調整
    [Aida_Bottom.kicad_pcb, Aida_Mid_Inside.kicad_pcb, Aida_Mid_Outside.kicad_pcb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]
